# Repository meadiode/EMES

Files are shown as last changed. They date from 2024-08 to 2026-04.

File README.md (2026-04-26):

# EMES - Epic Minimalist Entertainment System

**EMES** - is a very minimalistic DIY handheld game console. 

Work in progress.

EMES has the following specifications:

 - Screen: 15x10 pixels, LED
 - Input: four button keyboard
 - Sound: Magnetic buzzer
 - Physical dimensions(approx): 40x32x14mm 
 - Removeable 8-pin cartridges

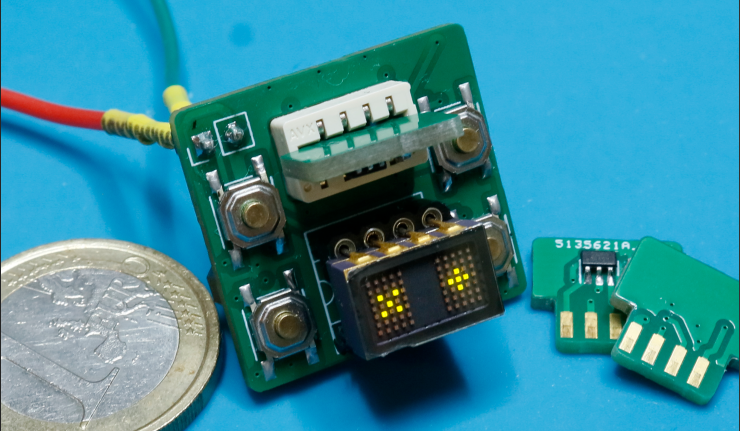
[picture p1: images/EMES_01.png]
EMES


The console doesn't have an onboard CPU/MCU, instead an MCU is placed on every removable cartridge.

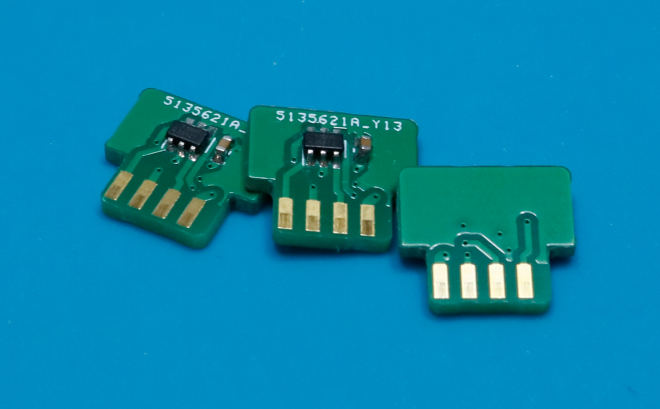
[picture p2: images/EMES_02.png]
Cartridges


Each cartridge features an ATTiny10 MCU with the following specs:

 - Speed 8MHz
 - Peogram/data flash: 1KB
 - RAM: 32 bytes
 - IO: 4
 - ADC: 8bit

## Games

 - Pong
 - Snek - a snake variant, edge wrapping
 - Egg -  a N1ntend0 Game & Watch-like egg-catching game 
 - Brik - a Tetris-like
 - Simon - Simon Says

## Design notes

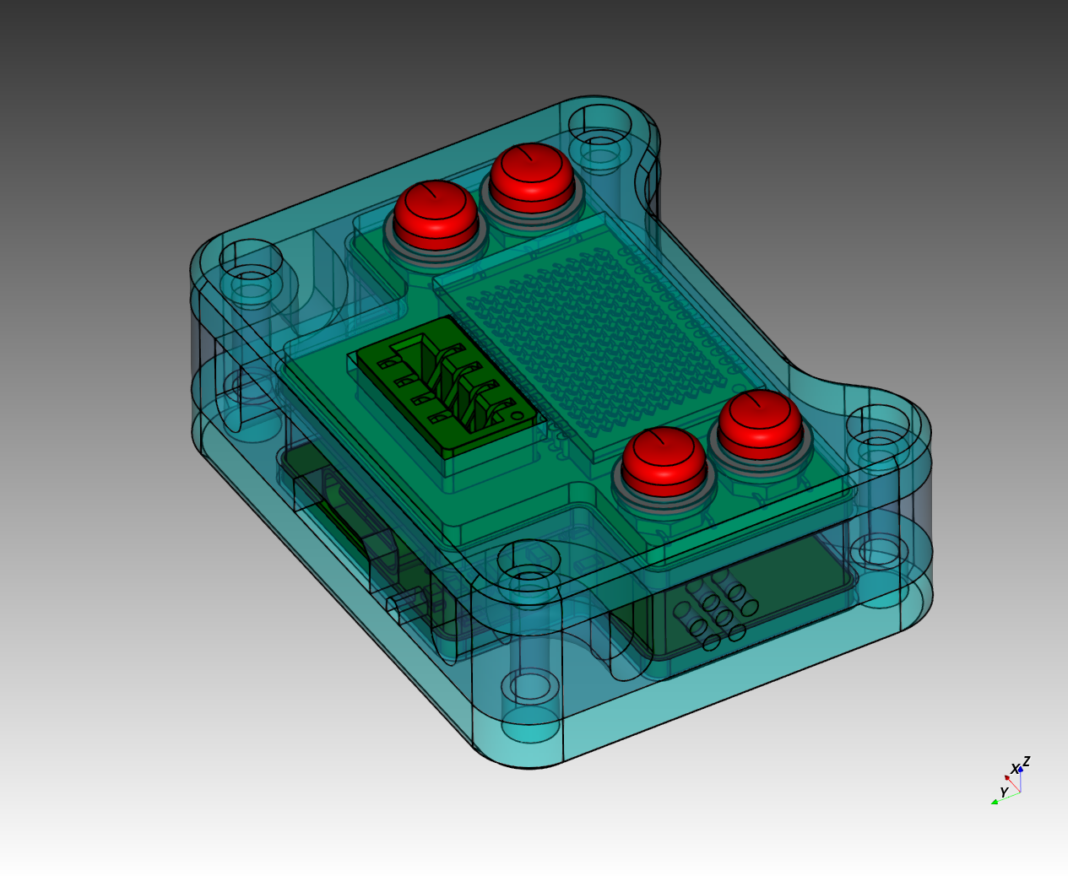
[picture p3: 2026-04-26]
images/housing_cad_01.png

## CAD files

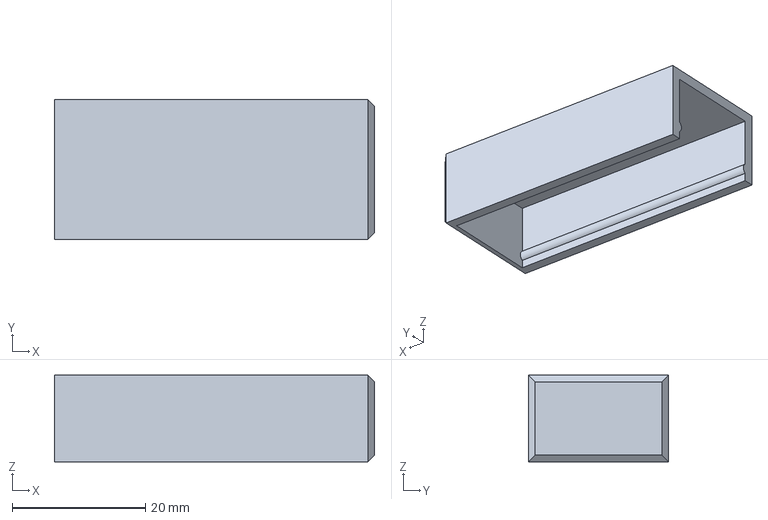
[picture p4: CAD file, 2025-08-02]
3dcad/cartridge_storage_box/cartridge_storage_box_cover.stp
48.0 x 21.0 x 13.0 mm

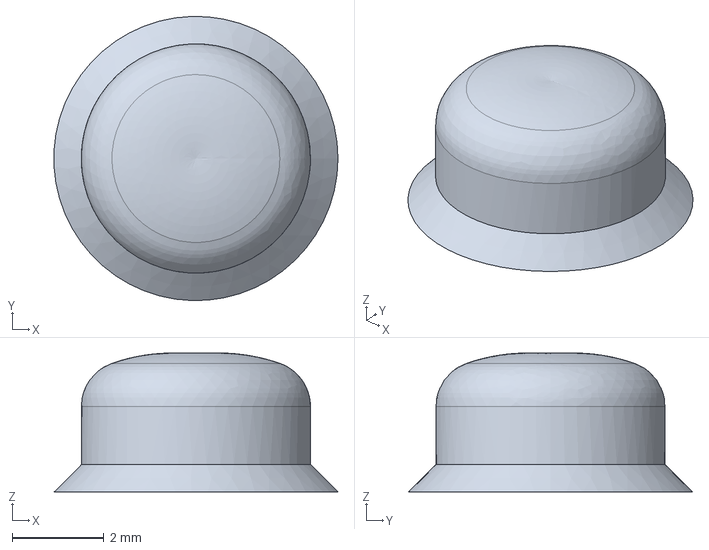
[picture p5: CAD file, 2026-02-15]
3dcad/housing/button.stp
6.19 x 6.20 x 3.03 mm

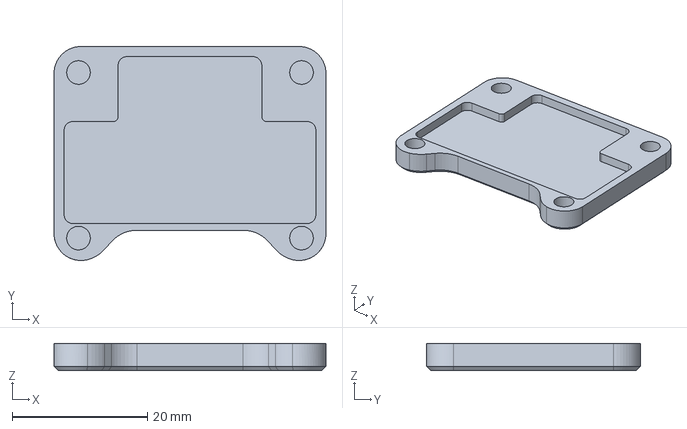
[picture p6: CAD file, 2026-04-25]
3dcad/housing/fdm/fdm_housing_bottom.stp
40.2 x 31.7 x 4.00 mm

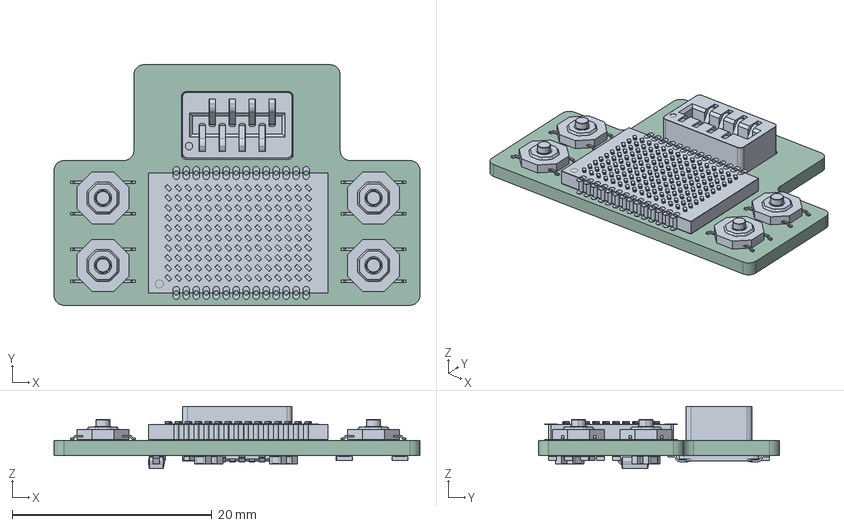
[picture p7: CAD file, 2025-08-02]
3dcad/housing/refs/base_board2.step
36.7 x 24.1 x 6.25 mm
TS18-5-20-SL-260-SMT-TR x 4
LED_0201_0603Metric x 150
display_matrix_copper
display_matrix_pad
display_matrix_via
display_matrix_silkscreen
display_matrix_soldermask
display_matrix_PCB
R_0603_1608Metric x 10
C_0603_1608Metric x 4
D_SOD-123
base_board2_PCB

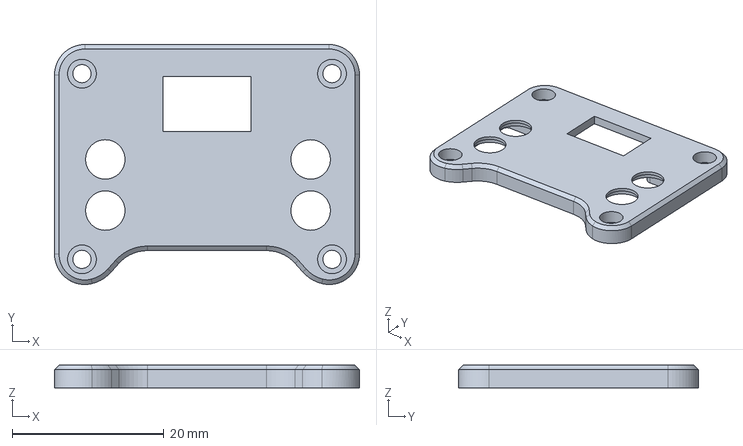
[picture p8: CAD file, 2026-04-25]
3dcad/housing/sla/sla_housing_top.stp
40.2 x 31.7 x 3.00 mm

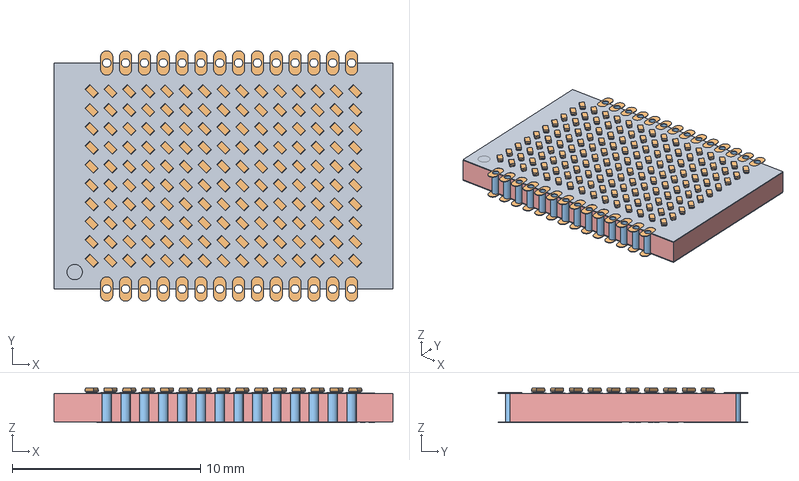
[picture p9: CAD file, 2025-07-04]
kicad/display_matrix/display_matrix.step
18.0 x 13.3 x 1.84 mm
LED_0201_0603Metric x 150
display_matrix_copper
display_matrix_pad
display_matrix_via
display_matrix_silkscreen
display_matrix_soldermask
display_matrix_PCB

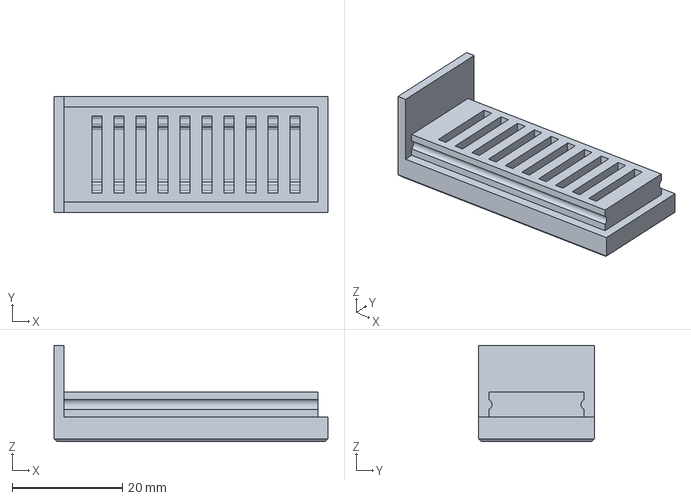
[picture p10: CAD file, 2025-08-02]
3dcad/cartridge_storage_box/cartridge_storage_box.stp
49.8 x 21.0 x 17.5 mm

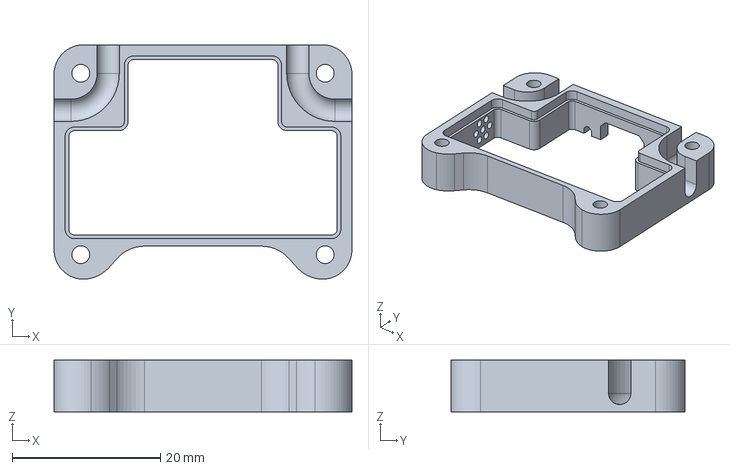
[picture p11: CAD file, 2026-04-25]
3dcad/housing/fdm/fdm_housing_middle.stp
40.2 x 31.7 x 7.00 mm

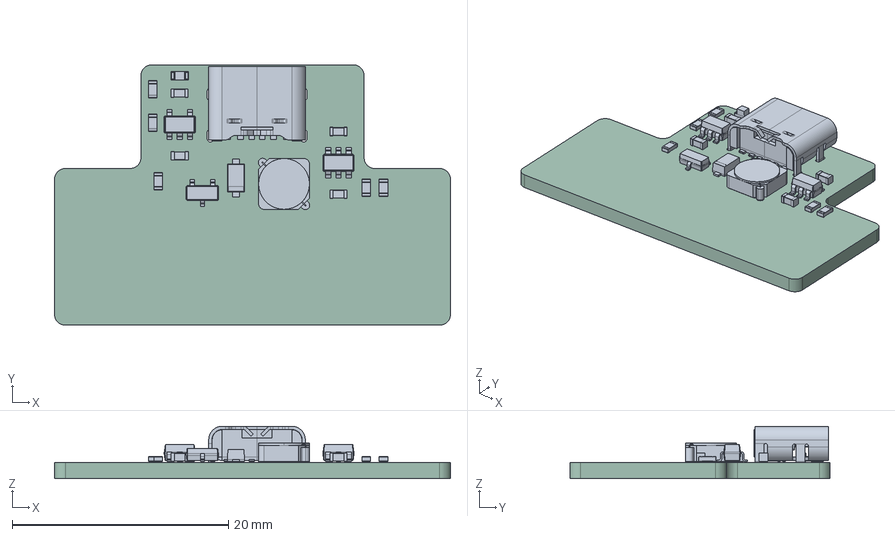
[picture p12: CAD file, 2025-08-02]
3dcad/housing/refs/power_supply.step
36.6 x 24.1 x 4.85 mm
SOT-23-5
R_0603_1608Metric x 5
C_0603_1608Metric x 4
LED_0603_1608Metric
SOT-23-6
D_SOD-123F
CDRH4D18NP-3R3NC
SOT-23
USB_C_Receptacle_GCT_USB4125-xx-x_6P_TopMnt_Horizontal
power_supply_PCB

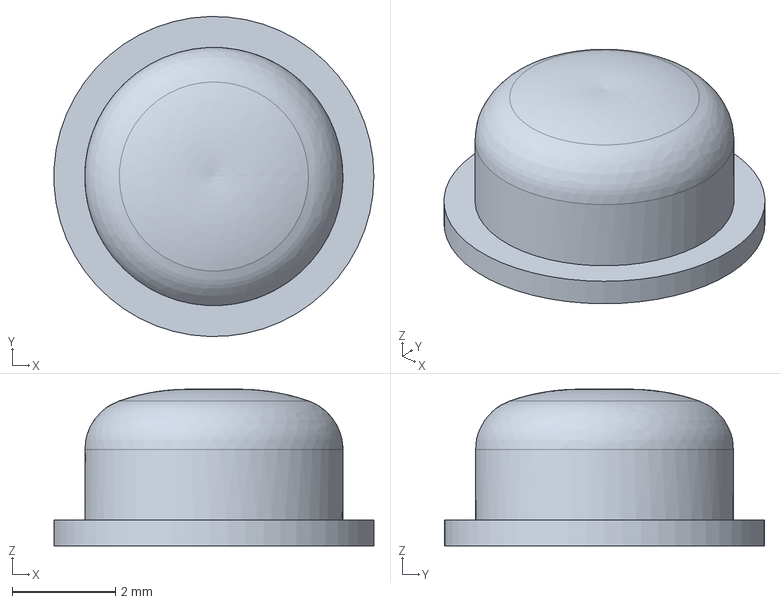
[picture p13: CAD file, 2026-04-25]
3dcad/housing/fdm/fdm_button.stp
6.19 x 6.20 x 3.03 mm

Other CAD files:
3dcad/housing/sla/sla_housing_middle.stp
3dcad/housing/sla/sla_housing_bottom.stp
3dcad/housing/fdm/fdm_housing_top.stp
3dcad/housing/sla/sla_button.stp

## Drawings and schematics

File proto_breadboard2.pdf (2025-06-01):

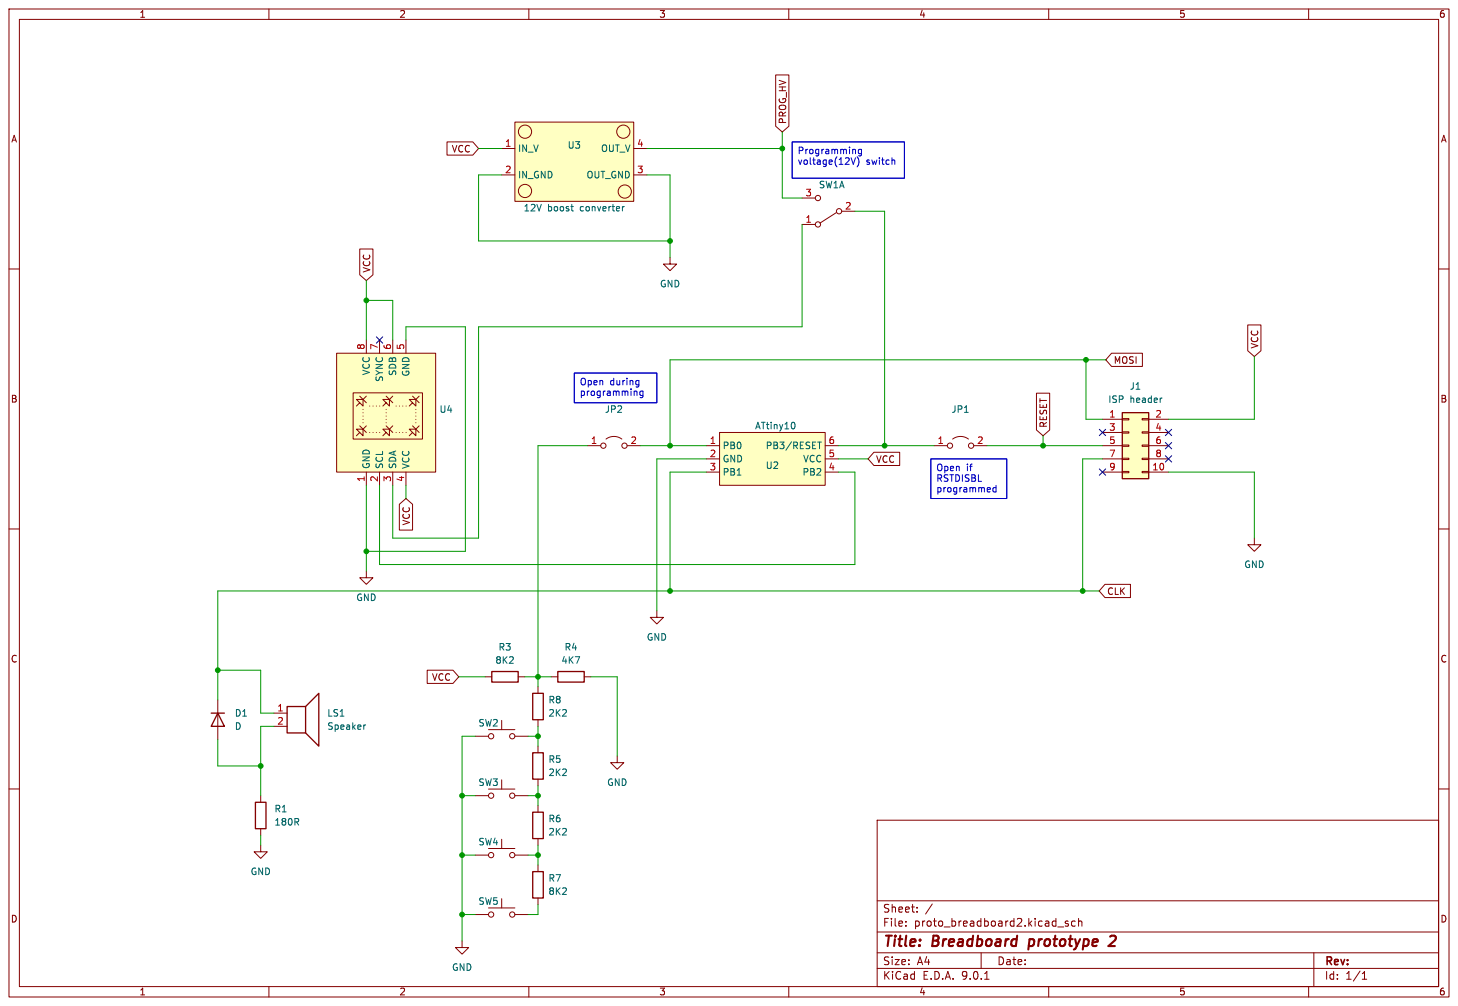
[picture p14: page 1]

Id: 1/1 Title: Breadboard prototype 2

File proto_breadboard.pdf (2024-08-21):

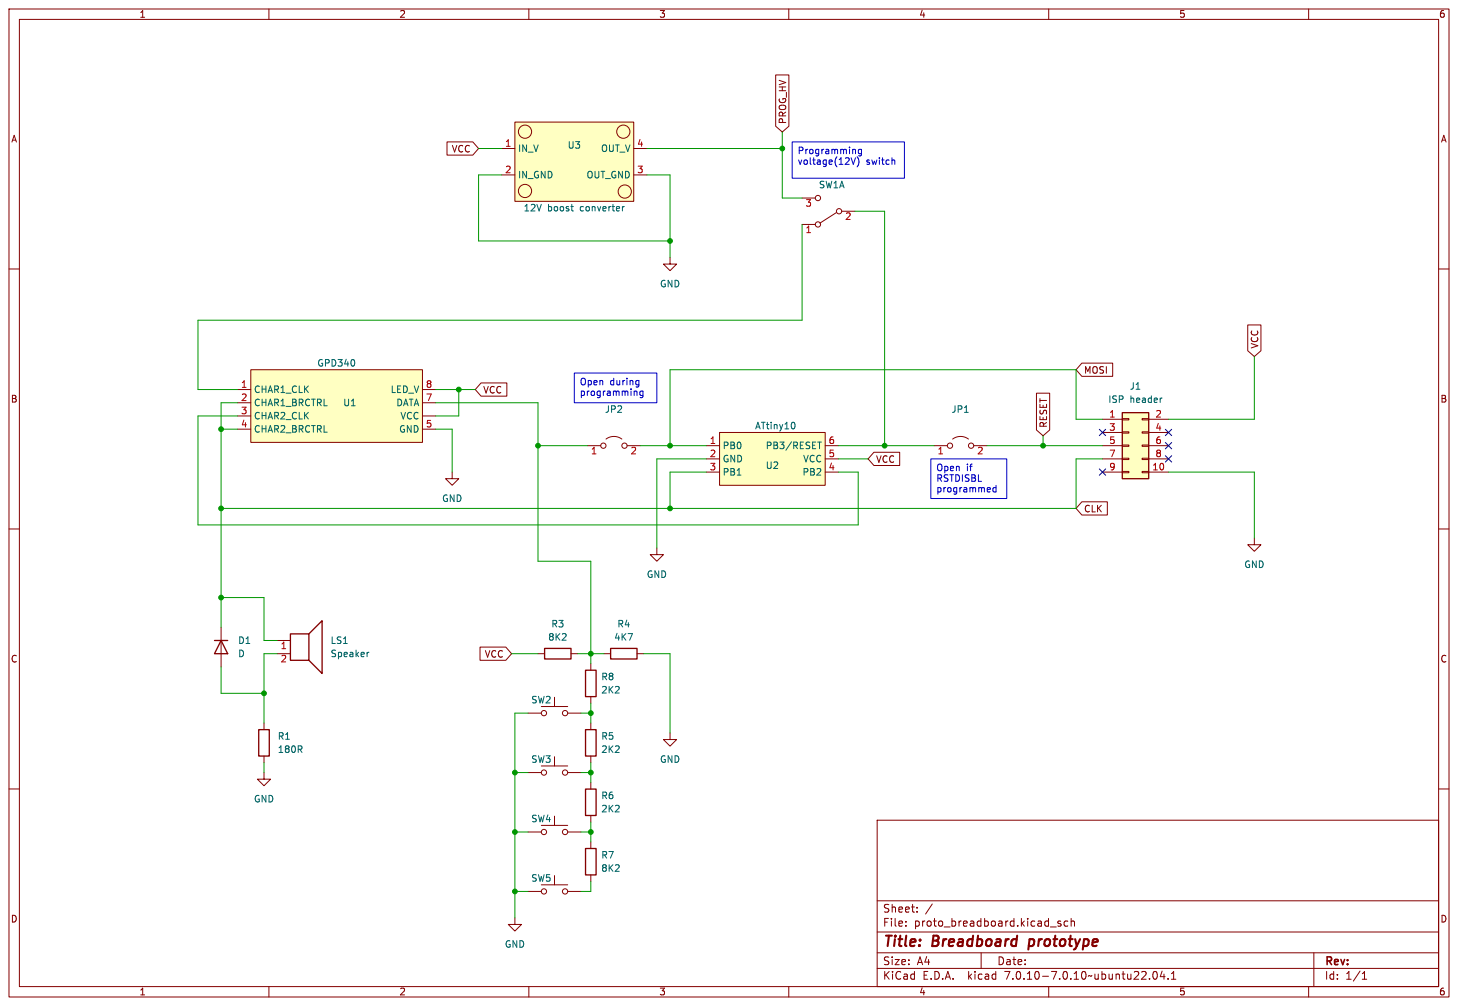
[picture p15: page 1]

Id: 1/1 Title: Breadboard prototype

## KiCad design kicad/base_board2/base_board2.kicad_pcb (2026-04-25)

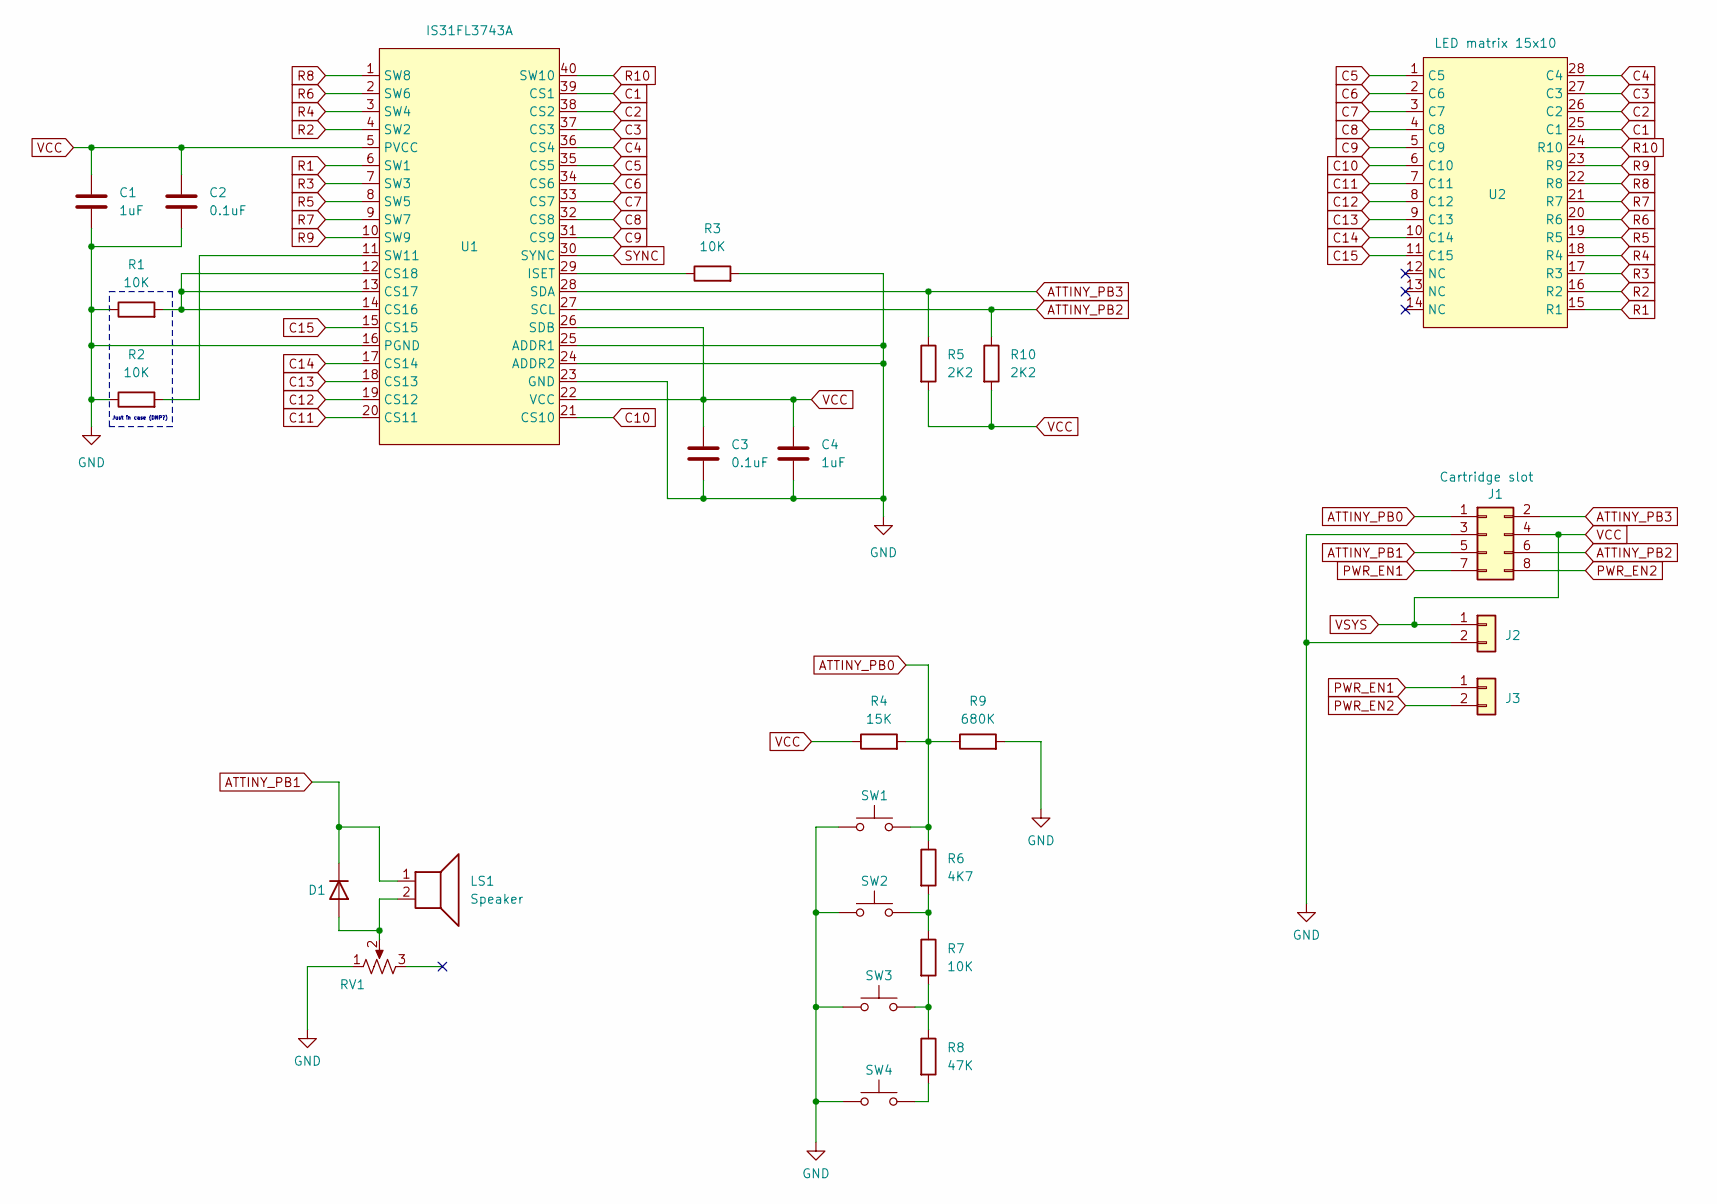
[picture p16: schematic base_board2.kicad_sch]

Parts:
C1, C4: 1uF; C_0603_1608Metric
C2, C3: 0.1uF; C_0603_1608Metric
D1: D; D_SOD-123
J1: Conn_02x04_Odd_Even; card_edge_2x4
J2, J3: Conn_01x02; Pads_1x2mm_2x
LS1: Speaker; Speaker_28908A
R1, R2, R3, R7: 10K; R_0603_1608Metric
R4: 15K; R_0603_1608Metric
R5, R10: 2K2; R_0603_1608Metric
R6: 4K7; R_0603_1608Metric
R8: 47K; R_0603_1608Metric
R9: 680K; R_0603_1608Metric
RV1: R_Potentiometer_US; ST-4EA
SW1, SW2, SW3, SW4: SW_Push; TS18_TACTILE_SWITCH
U1: IS31FL3743A; UQFN-40
U2: LED matrix 15x10; led_matrix_pcb_pads

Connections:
ATTINY_PB0: J1.1, R4.2, R6.1, R9.1, SW1.2
ATTINY_PB1: D1.1 (K), J1.5, LS1.1
ATTINY_PB2: J1.6, R10.1, U1.27 (SCL)
ATTINY_PB3: J1.2, R5.1, U1.28 (SDA)
C1: U1.39 (CS1), U2.25 (C1)
C2: U1.38 (CS2), U2.26 (C2)
C3: U1.37 (CS3), U2.27 (C3)
C4: U1.36 (CS4), U2.28 (C4)
C5: U1.35 (CS5), U2.1 (C5)
C6: U1.34 (CS6), U2.2 (C6)
C7: U1.33 (CS7), U2.3 (C7)
C8: U1.32 (CS8), U2.4 (C8)
C9: U1.31 (CS9), U2.5 (C9)
C10: U1.21 (CS10), U2.6 (C10)
C11: U1.20 (CS11), U2.7 (C11)
C12: U1.19 (CS12), U2.8 (C12)
C13: U1.18 (CS13), U2.9 (C13)
C14: U1.17 (CS14), U2.10 (C14)
C15: U1.15 (CS15), U2.11 (C15)
GND: C1.2, C2.2, C3.2, C4.2, J1.3, J2.2, R1.1, R2.1, R3.2, R9.2, RV1.1, SW1.1, SW2.1, SW3.1, SW4.1, U1.16 (PGND), U1.23 (GND), U1.24 (ADDR2), U1.25 (ADDR1)
unnamed: D1.2 (A), LS1.2, RV1.2
unnamed: R6.2, R7.1, SW2.2
unnamed: R7.2, R8.1, SW3.2
unnamed: R8.2, SW4.2
unnamed: R1.2, U1.12 (CS18), U1.13 (CS17), U1.14 (CS16)
unnamed: R3.1, U1.29 (ISET)
unnamed: R2.2, U1.11 (SW11)
PWR_EN1: J1.7, J3.1
PWR_EN2: J1.8, J3.2
R1: U1.6 (SW1), U2.15 (R1)
R2: U1.4 (SW2), U2.16 (R2)
R3: U1.7 (SW3), U2.17 (R3)
R4: U1.3 (SW4), U2.18 (R4)
R5: U1.8 (SW5), U2.19 (R5)
R6: U1.2 (SW6), U2.20 (R6)
R7: U1.9 (SW7), U2.21 (R7)
R8: U1.1 (SW8), U2.22 (R8)
R9: U1.10 (SW9), U2.23 (R9)
R10: U1.40 (SW10), U2.24 (R10)
SYNC: U1.30 (SYNC)
VCC: C1.1, C2.1, C3.1, C4.1, J1.4, J2.1, R4.1, R5.2, R10.2, U1.5 (PVCC), U1.22 (VCC), U1.26 (SDB)

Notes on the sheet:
Just in case (DNP?)

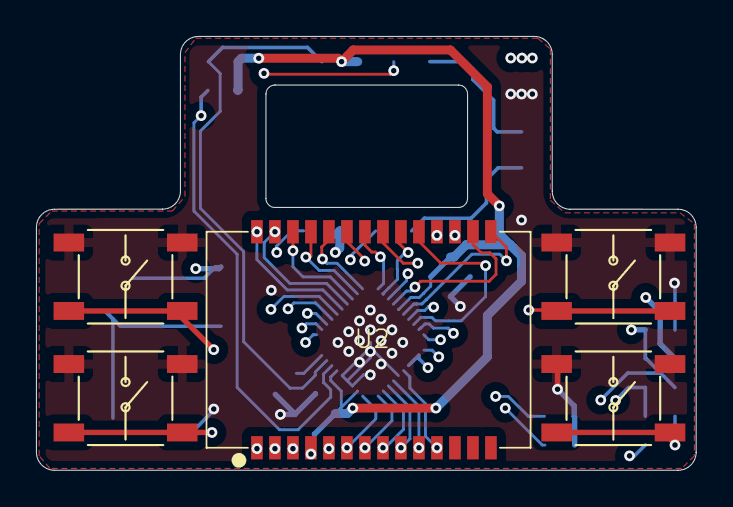
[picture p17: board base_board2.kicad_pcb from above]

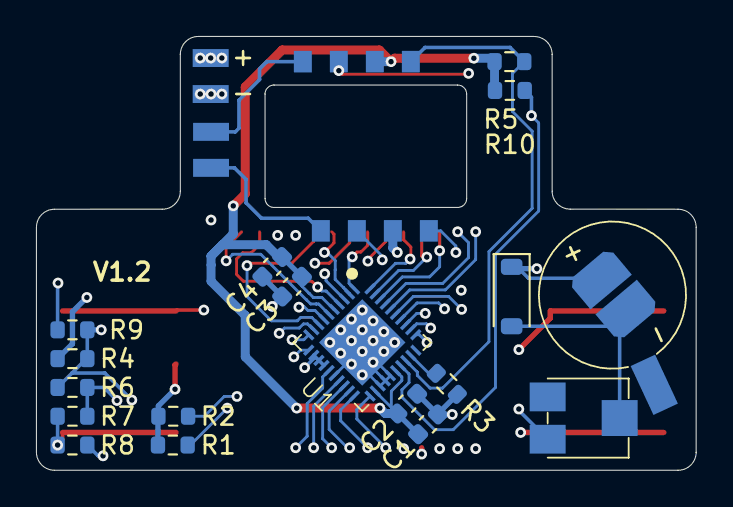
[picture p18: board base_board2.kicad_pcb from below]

Board: 4 copper layers, 36.7 x 24.1 mm, 26 parts (21 on the bottom side), 40 nets.

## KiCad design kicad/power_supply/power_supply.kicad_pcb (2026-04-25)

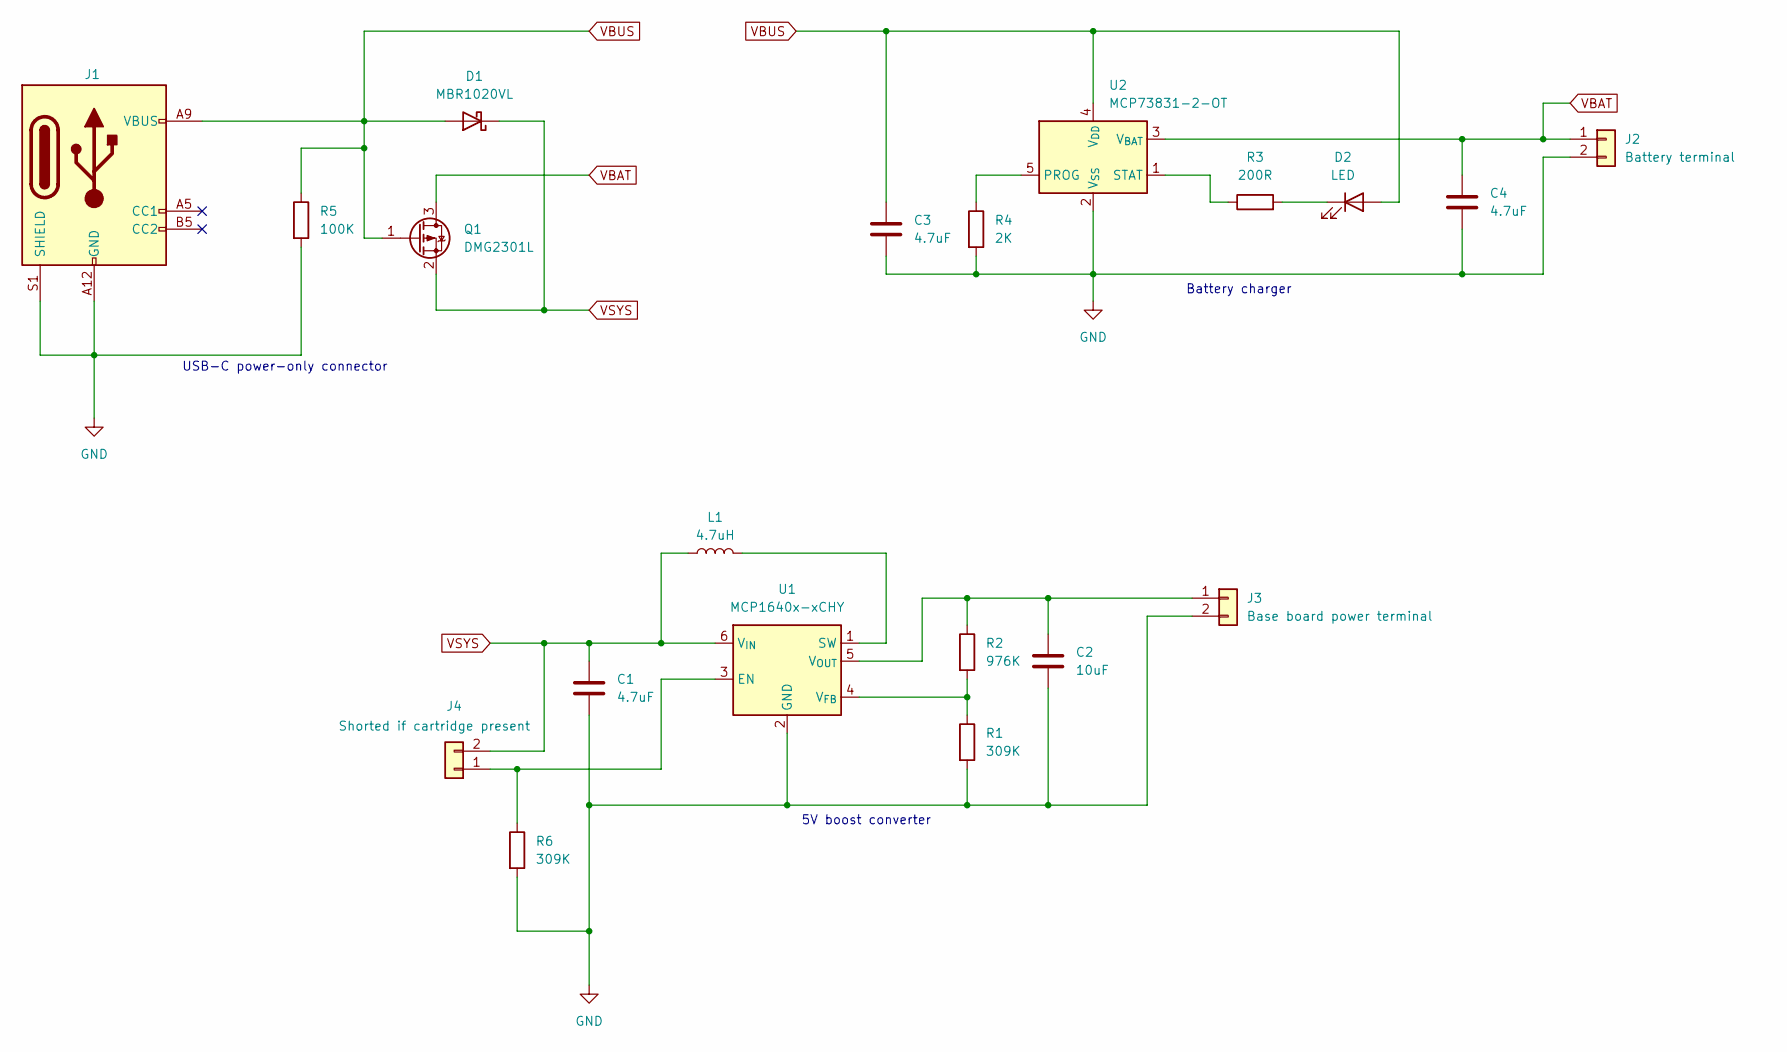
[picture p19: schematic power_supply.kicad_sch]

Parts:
C1, C3, C4: 4.7uF; C_0603_1608Metric
C2: 10uF; C_0603_1608Metric
D1: MBR1020VL; D_SOD-123F
D2: LED; LED_0603_1608Metric
J1: USB_C_Receptacle_PowerOnly_6P; USB_C_Receptacle_GCT_USB4125-xx-x_6P_TopMnt_Horizontal
J2: Battery terminal; Pads_1x2mm_2x
J3: Base board power terminal; Pads_1x2mm_2x
J4: Shorted if cartridge present; Pads_1x2mm_2x
L1: 4.7uH; L_Coilcraft_XAL5050-XXX
Q1: DMG2301L; SOT-23
R1, R6: 309K; R_0603_1608Metric
R2: 976K; R_0603_1608Metric
R3: 200R; R_0603_1608Metric
R4: 2K; R_0603_1608Metric
R5: 100K; R_0603_1608Metric
U1: MCP1640x-xCHY; SOT-23-6
U2: MCP73831-2-OT; SOT-23-5

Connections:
GND: C1.2, C2.2, C3.2, C4.2, J1.A12 (GND), J1.B12 (GND), J1.S1 (SHIELD), J2.2, J3.2, R1.2, R4.2, R5.2, R6.2, U1.2 (GND), U2.2 (V_{SS})
unnamed: D2.1 (K), R3.2
unnamed: C2.1, J3.1, R2.1, U1.5 (V_{OUT})
unnamed: J4.1, R6.1, U1.3 (EN)
unnamed: L1.2, U1.1 (SW)
unnamed: R1.1, R2.2, U1.4 (V_{FB})
unnamed: R4.1, U2.5 (PROG)
unnamed: R3.1, U2.1 (STAT)
VBAT: C4.1, J2.1, Q1.3 (D), U2.3 (V_{BAT})
VBUS: C3.1, D1.2 (A), D2.2 (A), J1.A9 (VBUS), J1.B9 (VBUS), Q1.1 (G), R5.1, U2.4 (V_{DD})
VSYS: C1.1, D1.1 (K), J4.2, L1.1, Q1.2 (S), U1.6 (V_{IN})

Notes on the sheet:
USB-C power-only connector
Battery charger
5V boost converter

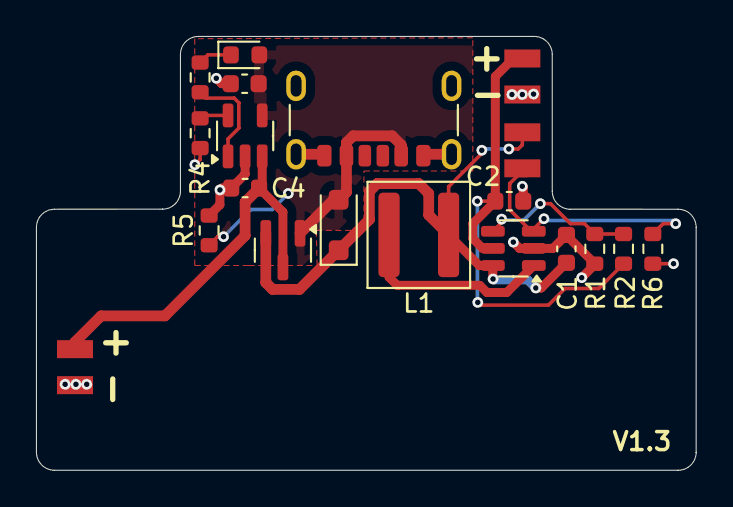
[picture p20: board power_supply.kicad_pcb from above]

Board: 2 copper layers, 36.6 x 24.1 mm, 20 parts (0 on the bottom side), 11 nets.

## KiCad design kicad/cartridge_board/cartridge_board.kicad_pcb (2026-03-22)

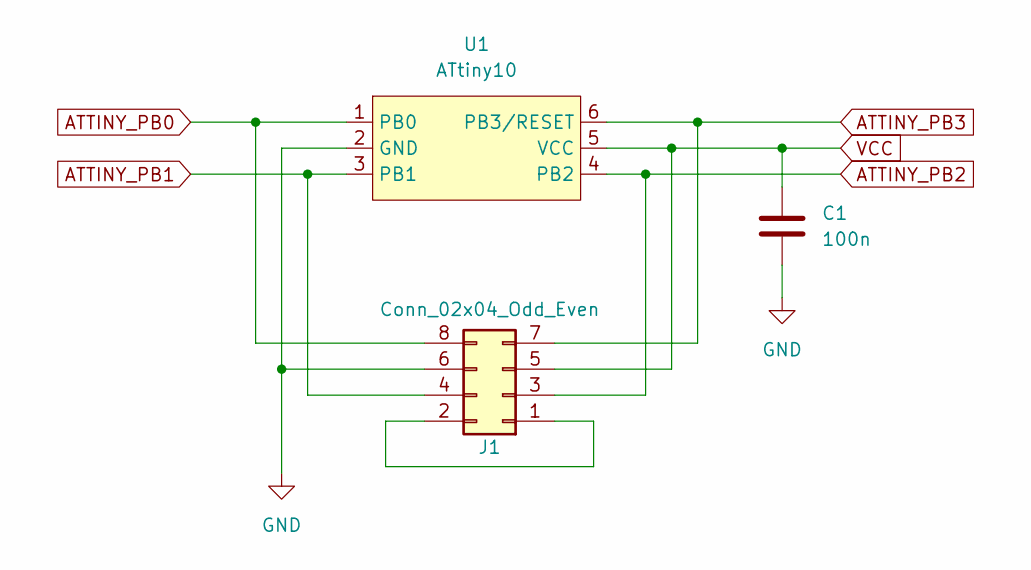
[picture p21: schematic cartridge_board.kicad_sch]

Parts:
C1: 100n; C_0603_1608Metric
J1: Conn_02x04_Odd_Even; board_edge_2x4
U1: ATtiny10; SOT-23-6

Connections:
ATTINY_PB0: J1.8, U1.1 (PB0)
ATTINY_PB1: J1.4, U1.3 (PB1)
ATTINY_PB2: J1.3, U1.4 (PB2)
ATTINY_PB3: J1.7, U1.6 (PB3/RESET)
GND: C1.2, J1.6, U1.2 (GND)
unnamed: J1.1, J1.2
VCC: C1.1, J1.5, U1.5 (VCC)

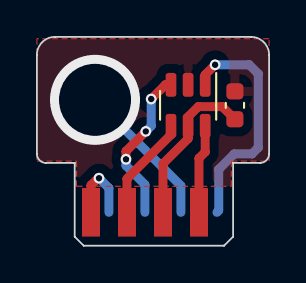
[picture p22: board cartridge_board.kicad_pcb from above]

Board: 4 copper layers, 12.9 x 11.6 mm, 3 parts (0 on the bottom side), 7 nets.

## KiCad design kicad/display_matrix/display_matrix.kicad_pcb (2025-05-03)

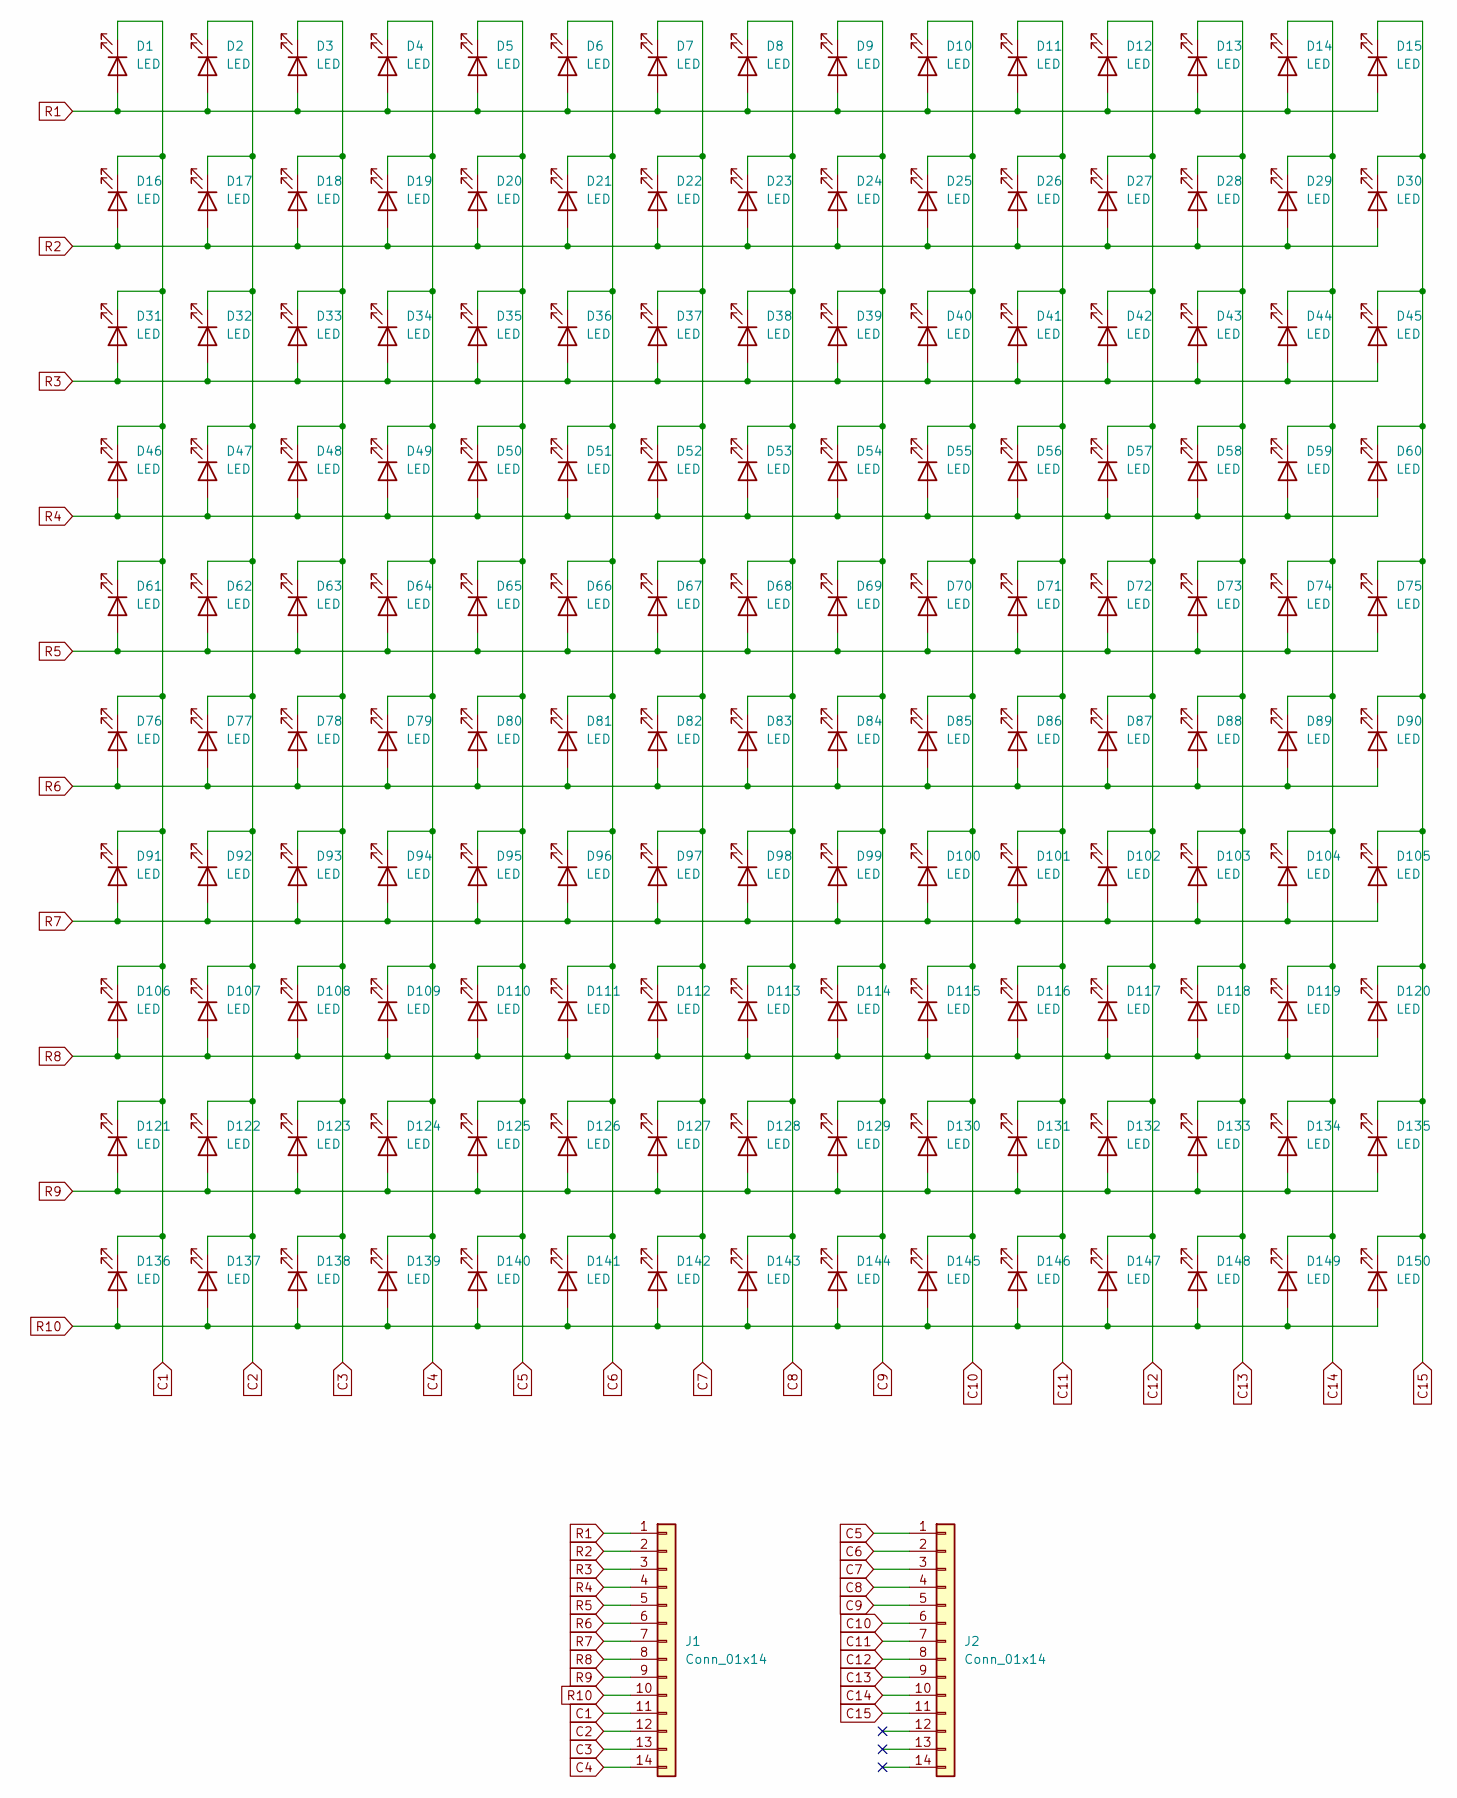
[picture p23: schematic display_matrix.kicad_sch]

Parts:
D1, D2, D3, D4, D5, D6, D7, D8, D9, D10, D11, D12, D13, D14, D15, D16, D17, D18, D19, D20, D21, D22, D23, D24, D25, D26, D27, D28, D29, D30, D31, D32, D33, D34, D35, D36, D37, D38, D39, D40, D41, D42, D43, D44, D45, D46, D47, D48, D49, D50, D51, D52, D53, D54, D55, D56, D57, D58, D59, D60, D61, D62, D63, D64, D65, D66, D67, D68, D69, D70, D71, D72, D73, D74, D75, D76, D77, D78, D79, D80, D81, D82, D83, D84, D85, D86, D87, D88, D89, D90, D91, D92, D93, D94, D95, D96, D97, D98, D99, D100, D101, D102, D103, D104, D105, D106, D107, D108, D109, D110, D111, D112, D113, D114, D115, D116, D117, D118, D119, D120, D121, D122, D123, D124, D125, D126, D127, D128, D129, D130, D131, D132, D133, D134, D135, D136, D137, D138, D139, D140, D141, D142, D143, D144, D145, D146, D147, D148, D149, D150: LED; LED_XL-0201UYC
J1, J2: Conn_01x14; Castellated_edge_14_1mm

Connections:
C1: D1.1 (K), D16.1 (K), D31.1 (K), D46.1 (K), D61.1 (K), D76.1 (K), D91.1 (K), D106.1 (K), D121.1 (K), D136.1 (K), J1.11
C2: D2.1 (K), D17.1 (K), D32.1 (K), D47.1 (K), D62.1 (K), D77.1 (K), D92.1 (K), D107.1 (K), D122.1 (K), D137.1 (K), J1.12
C3: D3.1 (K), D18.1 (K), D33.1 (K), D48.1 (K), D63.1 (K), D78.1 (K), D93.1 (K), D108.1 (K), D123.1 (K), D138.1 (K), J1.13
C4: D4.1 (K), D19.1 (K), D34.1 (K), D49.1 (K), D64.1 (K), D79.1 (K), D94.1 (K), D109.1 (K), D124.1 (K), D139.1 (K), J1.14
C5: D5.1 (K), D20.1 (K), D35.1 (K), D50.1 (K), D65.1 (K), D80.1 (K), D95.1 (K), D110.1 (K), D125.1 (K), D140.1 (K), J2.1
C6: D6.1 (K), D21.1 (K), D36.1 (K), D51.1 (K), D66.1 (K), D81.1 (K), D96.1 (K), D111.1 (K), D126.1 (K), D141.1 (K), J2.2
C7: D7.1 (K), D22.1 (K), D37.1 (K), D52.1 (K), D67.1 (K), D82.1 (K), D97.1 (K), D112.1 (K), D127.1 (K), D142.1 (K), J2.3
C8: D8.1 (K), D23.1 (K), D38.1 (K), D53.1 (K), D68.1 (K), D83.1 (K), D98.1 (K), D113.1 (K), D128.1 (K), D143.1 (K), J2.4
C9: D9.1 (K), D24.1 (K), D39.1 (K), D54.1 (K), D69.1 (K), D84.1 (K), D99.1 (K), D114.1 (K), D129.1 (K), D144.1 (K), J2.5
C10: D10.1 (K), D25.1 (K), D40.1 (K), D55.1 (K), D70.1 (K), D85.1 (K), D100.1 (K), D115.1 (K), D130.1 (K), D145.1 (K), J2.6
C11: D11.1 (K), D26.1 (K), D41.1 (K), D56.1 (K), D71.1 (K), D86.1 (K), D101.1 (K), D116.1 (K), D131.1 (K), D146.1 (K), J2.7
C12: D12.1 (K), D27.1 (K), D42.1 (K), D57.1 (K), D72.1 (K), D87.1 (K), D102.1 (K), D117.1 (K), D132.1 (K), D147.1 (K), J2.8
C13: D13.1 (K), D28.1 (K), D43.1 (K), D58.1 (K), D73.1 (K), D88.1 (K), D103.1 (K), D118.1 (K), D133.1 (K), D148.1 (K), J2.9
C14: D14.1 (K), D29.1 (K), D44.1 (K), D59.1 (K), D74.1 (K), D89.1 (K), D104.1 (K), D119.1 (K), D134.1 (K), D149.1 (K), J2.10
C15: D15.1 (K), D30.1 (K), D45.1 (K), D60.1 (K), D75.1 (K), D90.1 (K), D105.1 (K), D120.1 (K), D135.1 (K), D150.1 (K), J2.11
R1: D1.2 (A), D2.2 (A), D3.2 (A), D4.2 (A), D5.2 (A), D6.2 (A), D7.2 (A), D8.2 (A), D9.2 (A), D10.2 (A), D11.2 (A), D12.2 (A), D13.2 (A), D14.2 (A), D15.2 (A), J1.1
R2: D16.2 (A), D17.2 (A), D18.2 (A), D19.2 (A), D20.2 (A), D21.2 (A), D22.2 (A), D23.2 (A), D24.2 (A), D25.2 (A), D26.2 (A), D27.2 (A), D28.2 (A), D29.2 (A), D30.2 (A), J1.2
R3: D31.2 (A), D32.2 (A), D33.2 (A), D34.2 (A), D35.2 (A), D36.2 (A), D37.2 (A), D38.2 (A), D39.2 (A), D40.2 (A), D41.2 (A), D42.2 (A), D43.2 (A), D44.2 (A), D45.2 (A), J1.3
R4: D46.2 (A), D47.2 (A), D48.2 (A), D49.2 (A), D50.2 (A), D51.2 (A), D52.2 (A), D53.2 (A), D54.2 (A), D55.2 (A), D56.2 (A), D57.2 (A), D58.2 (A), D59.2 (A), D60.2 (A), J1.4
R5: D61.2 (A), D62.2 (A), D63.2 (A), D64.2 (A), D65.2 (A), D66.2 (A), D67.2 (A), D68.2 (A), D69.2 (A), D70.2 (A), D71.2 (A), D72.2 (A), D73.2 (A), D74.2 (A), D75.2 (A), J1.5
R6: D76.2 (A), D77.2 (A), D78.2 (A), D79.2 (A), D80.2 (A), D81.2 (A), D82.2 (A), D83.2 (A), D84.2 (A), D85.2 (A), D86.2 (A), D87.2 (A), D88.2 (A), D89.2 (A), D90.2 (A), J1.6
R7: D91.2 (A), D92.2 (A), D93.2 (A), D94.2 (A), D95.2 (A), D96.2 (A), D97.2 (A), D98.2 (A), D99.2 (A), D100.2 (A), D101.2 (A), D102.2 (A), D103.2 (A), D104.2 (A), D105.2 (A), J1.7
R8: D106.2 (A), D107.2 (A), D108.2 (A), D109.2 (A), D110.2 (A), D111.2 (A), D112.2 (A), D113.2 (A), D114.2 (A), D115.2 (A), D116.2 (A), D117.2 (A), D118.2 (A), D119.2 (A), D120.2 (A), J1.8
R9: D121.2 (A), D122.2 (A), D123.2 (A), D124.2 (A), D125.2 (A), D126.2 (A), D127.2 (A), D128.2 (A), D129.2 (A), D130.2 (A), D131.2 (A), D132.2 (A), D133.2 (A), D134.2 (A), D135.2 (A), J1.9
R10: D136.2 (A), D137.2 (A), D138.2 (A), D139.2 (A), D140.2 (A), D141.2 (A), D142.2 (A), D143.2 (A), D144.2 (A), D145.2 (A), D146.2 (A), D147.2 (A), D148.2 (A), D149.2 (A), D150.2 (A), J1.10

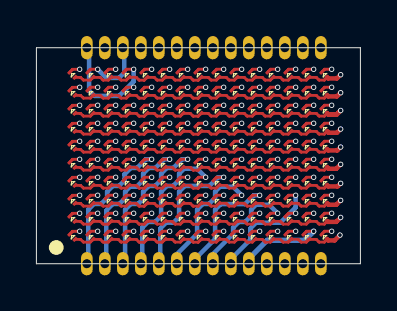
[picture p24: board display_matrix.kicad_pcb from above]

Board: 4 copper layers, 18.0 x 12.0 mm, 152 parts (0 on the bottom side), 25 nets.

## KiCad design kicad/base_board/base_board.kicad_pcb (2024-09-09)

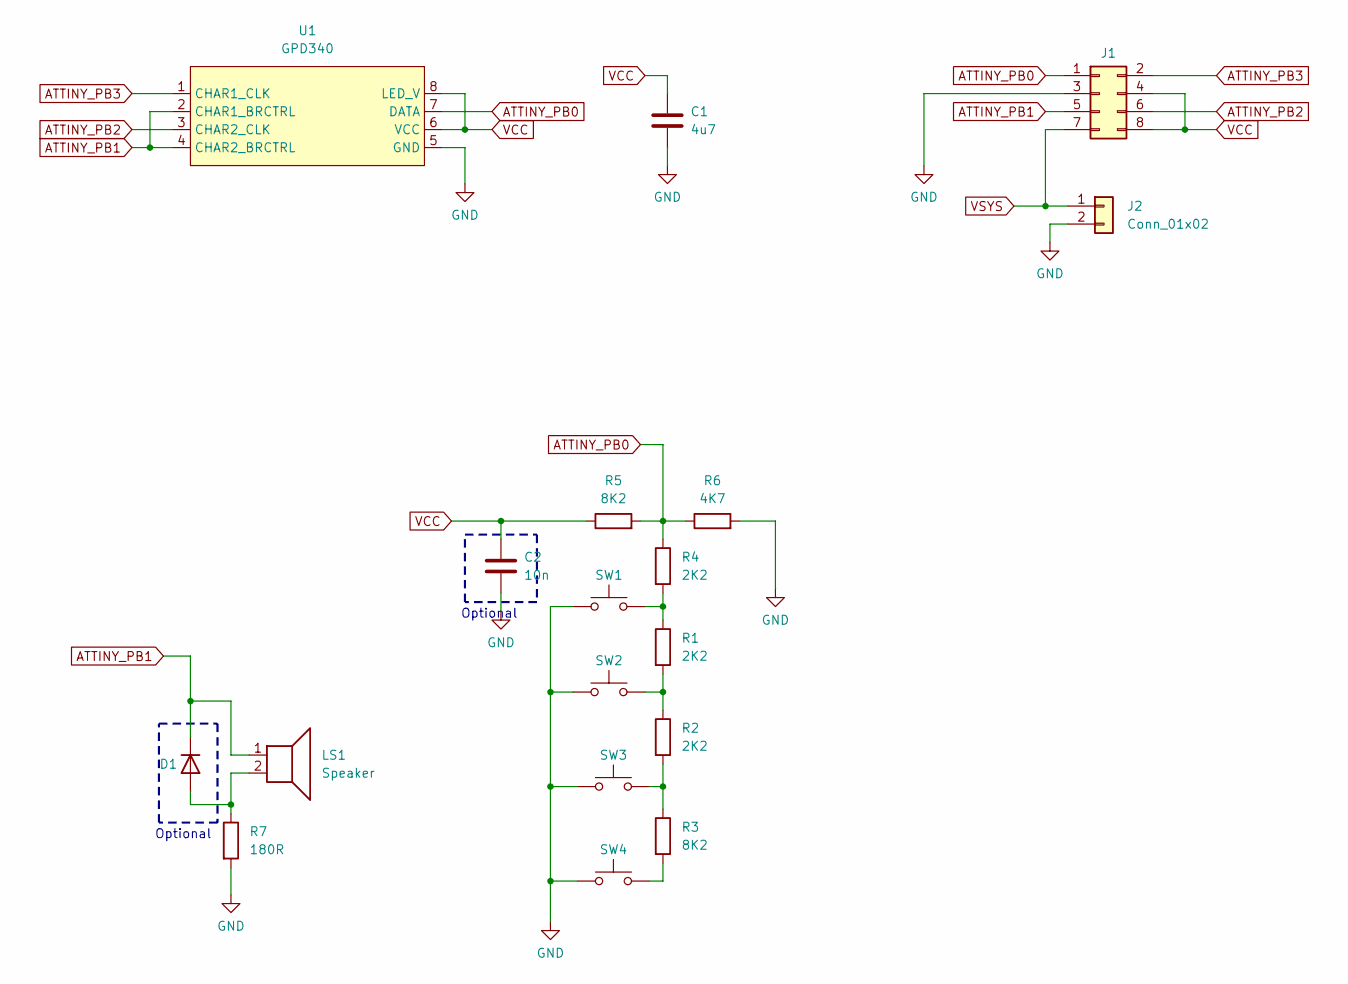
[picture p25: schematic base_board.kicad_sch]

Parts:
C1: 4u7; C_0603_1608Metric
C2: 10n; C_0603_1608Metric
D1: D; D_SOD-123
J1: Conn_02x04_Odd_Even; card_edge_2x4
J2: Conn_01x02; PinHeader_1x02_P2.54mm_Vertical
LS1: Speaker; BUZZER_CMT-0525
R1, R2, R4: 2K2; R_0603_1608Metric
R3, R5: 8K2; R_0603_1608Metric
R6: 4K7; R_0603_1608Metric
R7: 180R; R_0603_1608Metric
SW1, SW2, SW3, SW4: SW_Push; TS18_TACTILE_SWITCH
U1: GPD340; DIP-8_W7.62mm_Socket

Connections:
ATTINY_PB0: J1.1, R4.1, R5.2, R6.1, U1.7 (DATA)
ATTINY_PB1: D1.1 (K), J1.5, LS1.1, U1.2 (CHAR1_BRCTRL), U1.4 (CHAR2_BRCTRL)
ATTINY_PB2: J1.6, U1.3 (CHAR2_CLK)
ATTINY_PB3: J1.2, U1.1 (CHAR1_CLK)
GND: C1.2, C2.2, J1.3, J2.2, R6.2, R7.2, SW1.1, SW2.1, SW3.1, SW4.1, U1.5 (GND)
unnamed: D1.2 (A), LS1.2, R7.1
unnamed: R1.1, R4.2, SW1.2
unnamed: R1.2, R2.1, SW2.2
unnamed: R2.2, R3.1, SW3.2
unnamed: R3.2, SW4.2
VCC: C1.1, C2.1, J1.4, J1.8, R5.1, U1.6 (VCC), U1.8 (LED_V)
VSYS: J1.7, J2.1

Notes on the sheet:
Optional

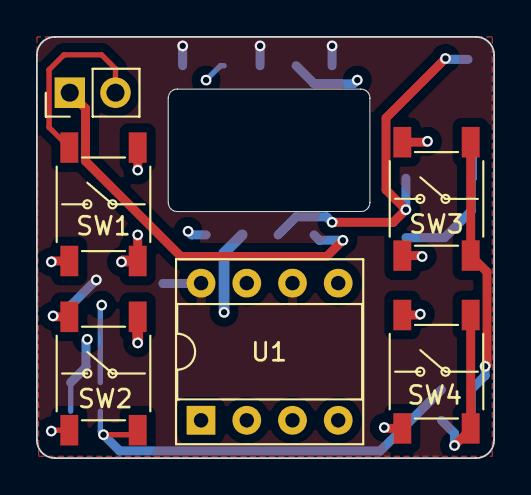
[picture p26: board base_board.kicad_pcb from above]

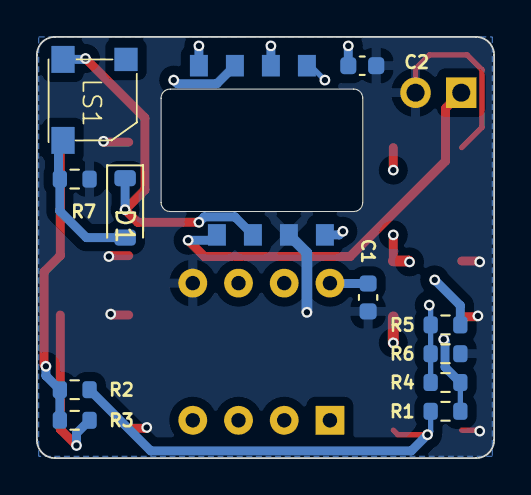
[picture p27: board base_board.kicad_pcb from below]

Board: 4 copper layers, 25.4 x 23.4 mm, 18 parts (12 on the bottom side), 12 nets.

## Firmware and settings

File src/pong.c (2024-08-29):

#include <avr/io.h>
#include <avr/interrupt.h>
#include <stdlib.h>
#include <stdbool.h>


/* B0: DISP_DATA, KEYBOARD */
/* B1: DISP_BR, BUZZER */
/* B2: DISP_CLK0 */
/* B3: DISP_CLK1 */


#define DDRB_ALL  0b00001111
#define DDRB_ADC  0b00001110

#define ABS(x) ((x) < 0 ? -(x) : (x))
#define MAX(a, b) ((a) > (b) ? (a) : (b))
#define MIN(a, b) ((a) > (b) ? (b) : (a))

static uint8_t kb_key = 0;
static uint8_t randn = 13;
static uint8_t dbuffer[9] = {42, 0, 13, 0};

static int8_t bpos_x;
static int8_t bpos_y;
static int8_t bdir_x;
static int8_t bdir_y;
static uint8_t bmov_x;
static uint8_t bmov_y;

static int8_t paddles[2] = {2, 3};
static uint8_t endgame = 1;
static uint8_t snd_timer = 0;

// void rng(void)
// {
//     randn = randn ^ (randn << 3);
//     randn = randn ^ (randn >> 1);
//     randn = randn ^ (randn << 5);
// }


void poll_kb(void)
{
    uint16_t samples = 0u;

    DDRB = DDRB_ADC;
    
    for (uint8_t i = 0; i < 4; i++)
    {
        ADCSRA |= (1 << ADSC); /* Start ADC conversion */

        while (ADCSRA & (1 << ADSC)) /* Wait till the conversion is ready */
        {
            asm("nop;");
        }

        samples += ADCL;
    }

    samples = samples / 4;


    if (40 <= samples && samples <= 44)
    {
        kb_key = 1;
    }
    else
    if (53 <= samples && samples <= 60)
    {
        kb_key = 2;
    }
    else
    if (61 <= samples && samples <= 69)
    {
        kb_key = 3;
    }
    else
    if (74 <= samples && samples <= 82)
    {
        kb_key = 4;
    }
    else
    {
        kb_key = 0;
    }

    DDRB = DDRB_ALL;
}


void beep(void)
{
    snd_timer = 10;
    ICR0 = 16000;
    OCR0B = 500;
}

void delay(void)
{
    for (uint8_t i = 0; i < 10; i++)
    {
        asm("nop;");
    }
}


void clear_buffer(void)
{
    for (uint8_t i = 0; i < sizeof(dbuffer); i++)
    {
        dbuffer[i] = 0;
    }
}

void put_pixel(int8_t x, int8_t y)
{
    if (x < 0 || y < 0 || (x >= 5 && x <= 7))
    {
        return;
    }

    uint8_t bn;

    if (x < 5)
    {
        bn = (6 - y) * 5 + (4 - x);
    }
    else
    {
        bn = 35 + (6 - y) * 5 + (4 - (x - 8));
    }

    dbuffer[bn >> 3] |= 1 << (bn & 7);
}


void draw_buffer(void)
{
    PORTB |= (1 << PORTB0);
    PORTB &= ~(1 << PORTB3) & 0x0f;
    delay();
    PORTB |= (1 << PORTB3);
    delay();

    for (uint8_t i = 0; i < 35; i++)
    {
        uint8_t bit = (dbuffer[i >> 3] >> (i & 0b111)) & 0x01;
        
        if (bit)
        {
            PORTB |= (1 << PORTB0);
        }
        else
        {
            PORTB &= ~(1 << PORTB0) & 0x0f;
        }

        PORTB &= ~(1 << PORTB3) & 0x0f;
        delay();
        PORTB |= (1 << PORTB3);
        delay();
    }

    PORTB |= (1 << PORTB0);
    PORTB &= ~(1 << PORTB2) & 0x0f;
    delay();
    PORTB |= (1 << PORTB2);
    delay();

    for (uint8_t i = 35; i < 70; i++)
    {
        uint8_t bit = (dbuffer[i >> 3] >> (i & 0b111)) & 0x01;
        
        if (bit)
        {
            PORTB |= (1 << PORTB0);
        }
        else
        {
            PORTB &= ~(1 << PORTB0) & 0x0f;
        }

        PORTB &= ~(1 << PORTB2) & 0x0f;
        delay();
        PORTB |= (1 << PORTB2);
        delay();
    }

}

void process(void)
{
    bmov_x += ABS(bdir_x);
    bmov_y += ABS(bdir_y);


    if (bmov_x >= 128)
    {
        bmov_x = 0;

        if (bdir_x > 0)
        {
            if (bpos_x >= 12)
            {
                bdir_x = -bdir_x;
                bpos_x--;
                beep();
                if ((bpos_y > paddles[1] + 1) || (bpos_y < paddles[1]))
                {
                    endgame = 1;
                }
            }
            else
            {
                bpos_x++;
            }
        }
        else if (bdir_x < 0)
        {
            if (bpos_x <= 0)
            {
                bdir_x = -bdir_x;
                bpos_x++;
                beep();
            }
            else
            {
                bpos_x--;
            }
        }
    }

    if (bmov_y >= 128)
    {
        bmov_y = 0;

        if (bdir_y > 0)
        {
            if (bpos_y >= 6)
            {
                bdir_y = -bdir_y;
                bpos_y--;
            }
            else
            {
                bpos_y++;
            }
        }
        else if (bdir_y < 0)
        {
            if (bpos_y <= 0)
            {
                bdir_y = -bdir_y;
                bpos_y++;
            }
            else
            {
                bpos_y--;
            }
        }
    }
}


int main()
{
    CCP = 0xd8;   /* Write configuration change protection signature - 0xD8*/
    CLKPSR = 0;   /* Set main clock prescaler to 1, resulting frequency is ~8MHz */
    
    ICR0 = 400;
    
    TCCR0A = (1 << COM0B1) | (1 << WGM01);
    TCCR0B = (1 << WGM03) | (1 << WGM02) | (1 << CS00);

    ADMUX  = 0;               /* Enable ADC input channel 0 - PB0 */
    ADCSRA |= (1 << ADEN);    /* Turn on the ADC */
    DIDR0  |= (1 << ADC0D);   /* Disable digital input on PB0 */

    DDRB = DDRB_ALL; /* Set all pins as outputs */

    PORTB = (1 << PORTB2) | (1 << PORTB3);

    OCR0A = 0;
    OCR0B = 50;

    uint8_t prev_kb_key = 0;

    for (;;)
    {
        poll_kb();

        if (kb_key != 0 && prev_kb_key == 0)
        {
            if (kb_key == 1 && paddles[1] > 0)
            {
                paddles[1]--;
            }

            if (kb_key == 2 && paddles[1] < 5)
            {
                paddles[1]++;
            }
        }

        // uint8_t pid = bdir_x > 0 ? 1 : 0;
        uint8_t pid = 0;
        int8_t dy = bpos_y - paddles[pid];

        if (dy < 0)
        {
            paddles[pid] = MAX(0, paddles[pid] - 1);
        }
        else if (dy > 0)
        {
            paddles[pid] = MIN(5, paddles[pid] + 1);
        }

        prev_kb_key = kb_key;

        clear_buffer();

        process();

        if (endgame)
        {
            endgame = 0;
            bpos_x = 1;
            bpos_y = 3;

            bdir_x = 24;
            bdir_y = 8;
            bmov_x = 0;
            bmov_y = 0;
        }

        put_pixel(bpos_x, bpos_y);
        put_pixel(0, paddles[0]);
        put_pixel(0, paddles[0] + 1);
        put_pixel(12, paddles[1]);
        put_pixel(12, paddles[1] + 1);

        draw_buffer();

        if (snd_timer)
        {
            snd_timer--;
            if (!snd_timer)
            {
                ICR0 = 400;
                OCR0B = 50;
            }
        }


        for (uint16_t i = 0; i < 2000; i++)
        {
            delay();
        }
    }
}

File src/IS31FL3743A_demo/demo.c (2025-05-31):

#include <pico/stdlib.h>
#include <hardware/gpio.h>
#include <hardware/pwm.h>
#include <hardware/i2c.h>
#include <stdio.h>
#include <string.h>

#define PIN_SDB 15
#define PIN_SDA 16
#define PIN_SCL 17

#define ADDR (0b01000000 >> 1)

#include "badapple.h"

#define BITBANG 1

void bitbang_i2c_write(uint8_t addr, const uint8_t *data, uint32_t size);
void bitbang_i2c_read(uint8_t addr, uint8_t *data, uint32_t size);


#ifdef BITBANG
# define is31_write(addr, data, size) bitbang_i2c_write(addr, data, size)
# define is31_read(addr, data, size) bitbang_i2c_read(addr, data, size)
#else
# define is31_write(addr, data, size) i2c_write_blocking(i2c0, addr, data, size, false)
# define is31_read(addr, data, size) i2c_read_blocking(i2c0, addr, data, size, false)
#endif


void is31_set_reg_page(uint8_t page_id)
{
    uint8_t data[2];

    /* Unlock the page-select register */
    data[0] = 0xfe;
    data[1] = 0xc5;
    is31_write(ADDR, data, 2);

    /* select page */
    data[0] = 0xfd;
    data[1] = page_id;
    is31_write(ADDR, data, 2);
}

void is31_init(void)
{
    uint8_t data[2];

    /* HW reset */
    gpio_put(PIN_SDB, false);
    sleep_ms(100);
    gpio_put(PIN_SDB, true);

    is31_set_reg_page(2);

    /* Configuration register */
    data[0] = 0x00;
    data[1] = 0x01;
    is31_write(ADDR, data, 2);

    /* Global Current Control register */
    data[0] = 0x01;
    data[1] = 0x70;
    is31_write(ADDR, data, 2);

    /* Pull up/down register config register */
    data[0] = 0x01;
    data[1] = 0x70;
    is31_write(ADDR, data, 2);


    is31_set_reg_page(1);

    /* Write scalling values */
    for (uint8_t i = 1; i <= 198; i++)
    {
        data[0] = i;
        data[1] = 0xff;

        is31_write(ADDR, data, 2);
    }

    is31_set_reg_page(0);

    /* Write PWMs */
    for (uint8_t i = 1; i <= 198; i++)
    {
        data[0] = i;
        data[1] = 0x00;

        is31_write(ADDR, data, 2);
    }
}

void is31_printout_config_registers(void)
{

    uint8_t data = 0xfc;
    uint8_t rdata = 0;

    is31_write(ADDR, &data, 1);
    is31_read(ADDR, &rdata, 1);

    printf("Device id: 0x%02X\n", rdata);

    is31_set_reg_page(2);

    const char* const regnames[] =
    {
        "Configureation register                 ",
        "Global Current Control register         ",
        "Pull Down/Up resistor selection register",
    };

    for (uint8_t reg_id = 0; reg_id < 3; reg_id++)
    {
        
        if (reg_id == 2)
        {
            gpio_put(18, 1);
        }
        is31_write(ADDR, &reg_id, 1);
        is31_read(ADDR, &rdata, 1);
        
        gpio_put(18, 0);

        printf("%s : 0x%02X\n", regnames[reg_id], rdata);
    }
}

void is31_set_pixel(uint8_t x, uint8_t y, uint8_t val)
{
    uint8_t data[2];

    data[0] = 1 + y * 18 + x; /* PWM reg id */
    data[1] = val;

    is31_write(ADDR, data, 2);
}

void bitbang_i2c_write(uint8_t addr, const uint8_t *data, uint32_t size)
{
    /* start condition */
    gpio_set_dir(PIN_SDA, false);
    gpio_set_dir(PIN_SCL, false);
    sleep_us(1);
    gpio_set_dir(PIN_SDA, true);
    sleep_us(1);

    for (uint32_t i = 0; i <= size; i++)
    {
        uint8_t byte;
        if (i == 0)
        {
            byte = addr << 1;         
        }
        else
        {
            byte = data[i - 1];
        }

        for (uint8_t j = 0; j < 8; j++)
        {
            gpio_set_dir(PIN_SDA, (byte & 0b10000000) == 0);
            gpio_set_dir(PIN_SCL, true);
            sleep_us(1);
            gpio_set_dir(PIN_SCL, false);
            sleep_us(1);
            byte <<= 1;
        }

        /* ACK cycle */
        gpio_set_dir(PIN_SDA, true);
        gpio_set_dir(PIN_SCL, true);
        sleep_us(1);
        gpio_set_dir(PIN_SCL, false);
        sleep_us(1);
        gpio_set_dir(PIN_SDA, false);
    }

    /* stop condition */
    gpio_set_dir(PIN_SDA, true);
    gpio_set_dir(PIN_SCL, true);
    sleep_us(1);
    gpio_set_dir(PIN_SCL, false);
    gpio_set_dir(PIN_SDA, true);
    sleep_us(1);
}


void bitbang_i2c_read(uint8_t addr, uint8_t *data, uint32_t size)
{
    /* start condition */
    gpio_set_dir(PIN_SDA, false);
    gpio_set_dir(PIN_SCL, false);
    sleep_us(1);
    gpio_set_dir(PIN_SDA, true);
    gpio_put(PIN_SDA, 0);
    sleep_us(1);

    uint8_t byte = (addr << 1) | 1;

    for (uint8_t j = 0; j < 8; j++)
    {
        gpio_set_dir(PIN_SDA, (byte & 0b10000000) == 0);
        gpio_set_dir(PIN_SCL, true);
        sleep_us(1);
        gpio_set_dir(PIN_SCL, false);
        sleep_us(1);
        byte <<= 1;
    }

    /* ACK cycle */
    gpio_set_dir(PIN_SCL, true);
    sleep_us(1);
    gpio_set_dir(PIN_SCL, false);
    sleep_us(1);
    gpio_set_dir(PIN_SDA, false);

    for (uint32_t i = 0; i < size; i++)
    {
        uint8_t rbyte = 0;
        for (uint8_t j = 0; j < 8; j++)
        {
            gpio_set_dir(PIN_SCL, true);
            sleep_us(1);
            rbyte |= (gpio_get(PIN_SDA) ? 1 : 0) << (7 - j);
            gpio_set_dir(PIN_SCL, false);
            sleep_us(1);
        }
        data[i] = rbyte;
    }

    /* ACK cycle */
    gpio_set_dir(PIN_SDA, true);
    gpio_put(PIN_SDA, 1);
    gpio_set_dir(PIN_SCL, true);
    sleep_us(1);
    gpio_set_dir(PIN_SCL, false);
    sleep_us(1);
    gpio_set_dir(PIN_SDA, false);

    /* stop condition */
    gpio_set_dir(PIN_SDA, true);
    gpio_put(PIN_SDA, 0);
    gpio_set_dir(PIN_SCL, true);
    sleep_us(1);
    gpio_set_dir(PIN_SCL, false);
    sleep_us(1);
    gpio_set_dir(PIN_SDA, false);
}


int main(void)
{
    stdio_init_all();

    printf("SW: %u\n", 4);
    
    gpio_init(PIN_SDB);
    gpio_init(PIN_SDA);
    gpio_init(PIN_SCL);
    
    gpio_init(18);
    gpio_set_dir(18, true);
    gpio_put(18, 0);

    i2c_init(i2c0, 100 * 1000);
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

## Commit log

2024-08-21 add breadboard kicad/pdf schematics
    [proto_breadboard.kicad_pcb, proto_breadboard.kicad_sch]
2024-08-21 drive speaker directly
    [proto_breadboard.kicad_sch]
2024-08-29 rewriting pong in assembly - almost there
2024-09-06 adjust keyboard ADC values; assembly pong: add score counter, paddle choice, start/end game
2024-09-09 add kicad projects for baseboard and cartridge
    [base_board.kicad_pcb, base_board.kicad_sch, cartridge_board.kicad_pcb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]
2025-05-03 work on LED matrix & driver PCBs
    [display_matrix.kicad_pcb, display_matrix.kicad_sch, matrix_driver_standalone.kicad_pcb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]
2025-05-11 minor PCB fixes - display led matrix, standalone driver module
    [matrix_driver_standalone.kicad_pcb]
2025-05-25 play bad apple; fix an oopsie in the driver schematics/pcb
    [matrix_driver_standalone.kicad_pcb, matrix_driver_standalone.kicad_sch]
2025-05-31 experiments with bitbanged i2c reading/writing
2025-06-01 new proto breadboard & initial demo for tiny10
    [proto_breadboard2.kicad_pcb, proto_breadboard2.kicad_sch]
2025-07-04 base_board-v2 & power_supply PCBs
    [base_board2.kicad_pcb, base_board2.kicad_sch, display_matrix.step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]
2025-07-18 playable brik.S; resistor ladder change for wider voltage gap between keys
    [base_board2.kicad_pcb, base_board2.kicad_sch, power_supply.kicad_pcb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]
2025-07-26 fix an oopsie on base_board2
    [base_board2.kicad_pcb, base_board2.kicad_sch]
2025-08-02 initial version of housing & cartridge storage container; minor changes in the PCBs; improve egg.S
    [base_board2.kicad_pcb, base_board2.step, button.stp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]
2025-08-03 3dcad/housing - smol adjustments & improvements
    [button.stp, housing_bottom.stp, housing_middle.stp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]
2025-08-17 3dcad/housing - better key chain hole with a snap joint
    [button.stp, housing_bottom.stp, housing_middle.stp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]
2026-02-14 pcbs: improve powering scheme, redesign cartridge; 3dcad: update whole housing
    [base_board2.kicad_pcb, base_board2.kicad_sch, cartridge_board.kicad_pcb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]
2026-02-15 3dcad/housing: top part blind version
    [button.stp, housing_bottom.stp, housing_middle.stp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]
2026-03-22 flip cartridge pcb
    [cartridge_board.kicad_pcb, cartridge_board.kicad_sch]
2026-03-22 cartridge pcb panelized; smol fixes to baseboard pcb
    [base_board2.kicad_pcb, cartridge_board.kicad_pcb, cartridge_board.kicad_sch]
2026-03-28 3dcad/housing - refactor; options for heatserts & blind top
2026-04-25 3dcad/housing: fdm & sla variants; kicad/power_supply: add p-down resistor to the MCP1640's EN pin
    [base_board2.kicad_pcb, cartridge_board.kicad_pcb, fdm_button.stp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]
2026-04-25 pong/snek/brik/test_util.S: small updates; brik.S: add speedup logic, game over tune
    [fdm_button.stp, fdm_housing_bottom.stp, fdm_housing_middle.stp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]
2026-04-26 update README & cad pictures
